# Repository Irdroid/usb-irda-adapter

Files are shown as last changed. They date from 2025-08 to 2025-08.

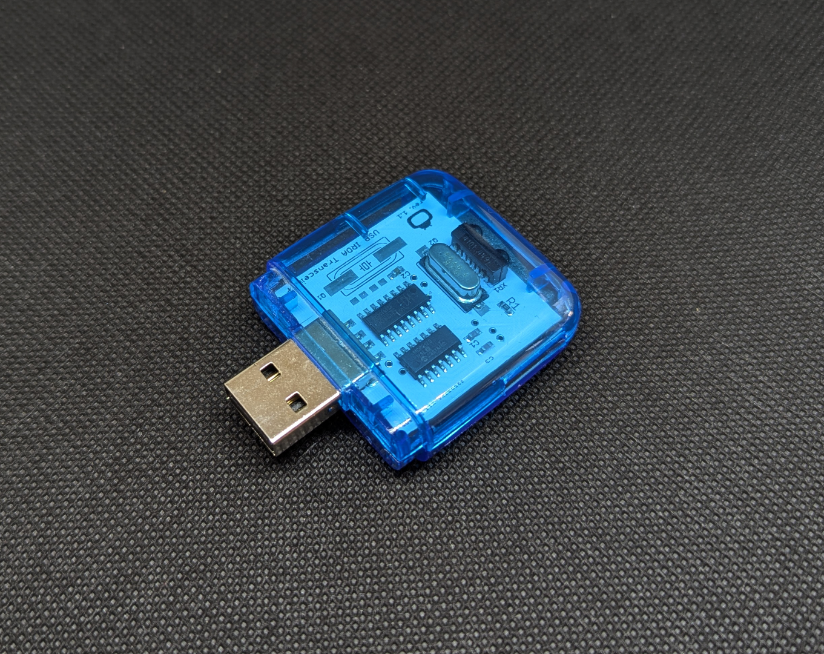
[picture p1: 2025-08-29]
Hardware/Pictures/irda_2 (Large).png

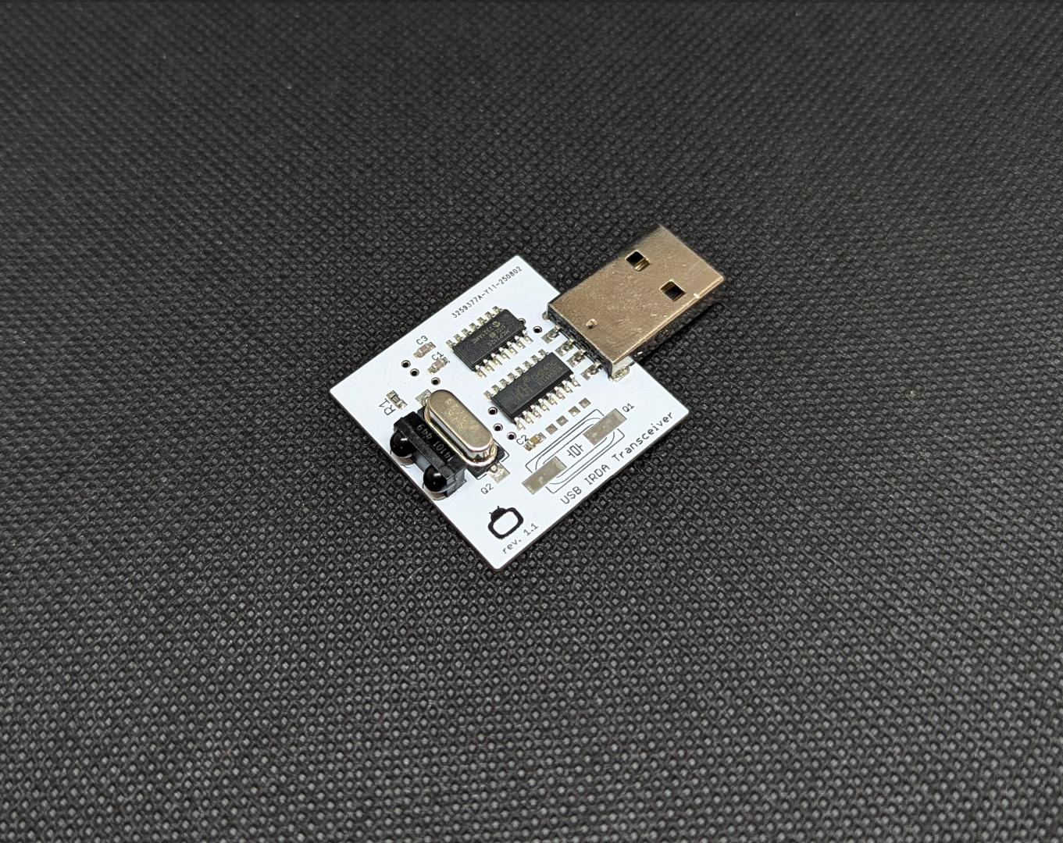
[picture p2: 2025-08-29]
Hardware/Pictures/irda_3 (Large).png

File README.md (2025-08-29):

# usb-irda-adapter
turns a USB port into an IrDA compliant infrared port for communication with IrDA devices on more recent operating systems

The USB irDA adapter is compatible with Windows 7, 10, 11 and Linux (older kernel versions, because the irDA stack was removed in recent kernel versions). 

Allows you to interface with irDA compliant devices, such as dive computers, medical instruments, power meters and more.

- Supports irDa SIR protocol (irDa spec. 1.3 )
- Supports Baud rates from 9600 to 115200
- Drivers for MS Windows 11 and 10
- USB 2.0 interface to the Host system.
- 2 meters line-of-sight irDa communication

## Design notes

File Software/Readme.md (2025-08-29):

USB irDA Adapter Device drivers for

- Windows 11
- Windows 10
- Windows 7

- [Installation instructions youtube video](https://www.youtube.com/watch?v=PCWln6I-PIc&t)

- [UWATEC dive computer irDa communication demo](https://www.youtube.com/watch?v=iUJTAUaZC4I)

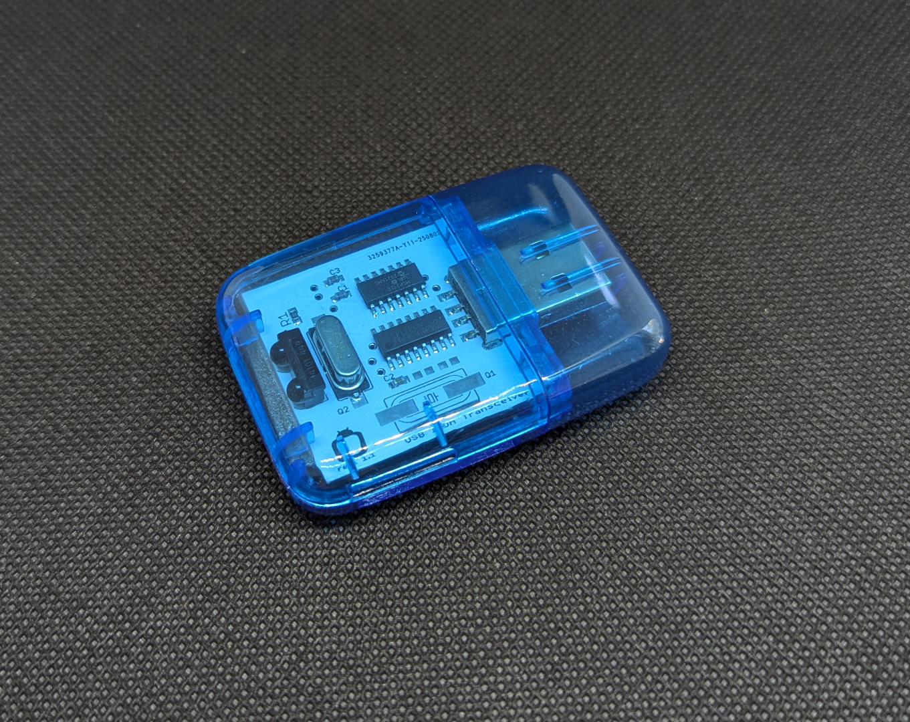
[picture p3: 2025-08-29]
Hardware/Pictures/irda_1 (Large).png

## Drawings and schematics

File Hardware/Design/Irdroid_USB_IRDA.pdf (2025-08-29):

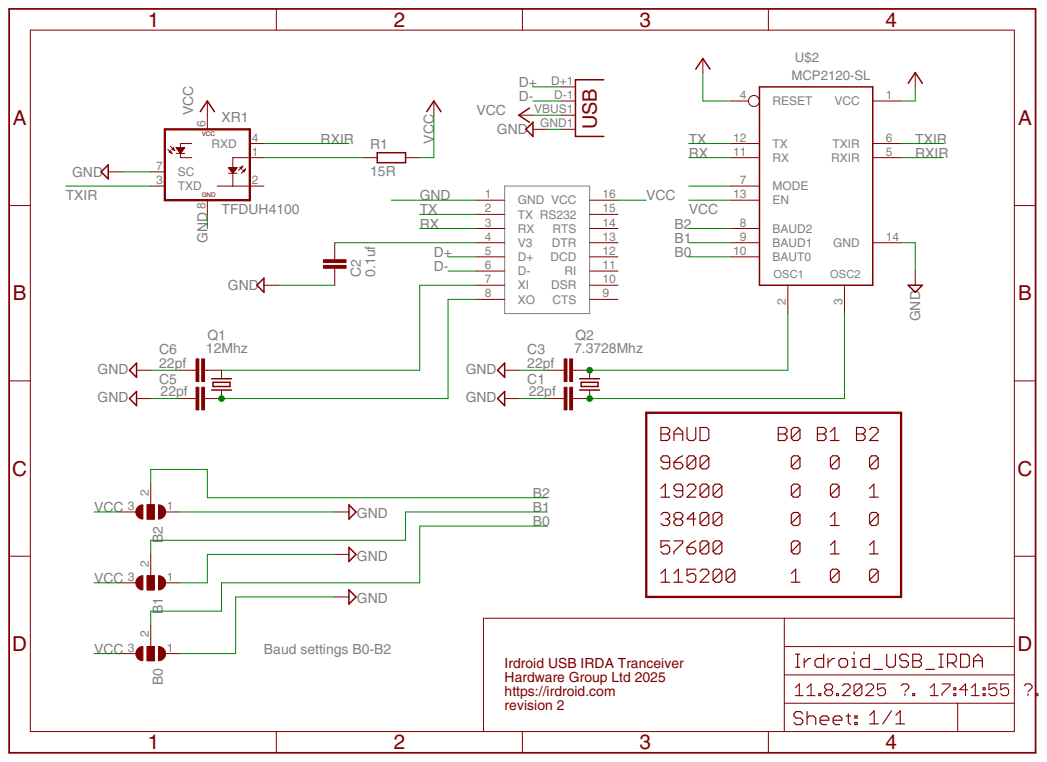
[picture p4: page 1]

Irdroid USB IRDA Tranceiver
Hardware Group Ltd 2025
https://irdroid.com
revision 2

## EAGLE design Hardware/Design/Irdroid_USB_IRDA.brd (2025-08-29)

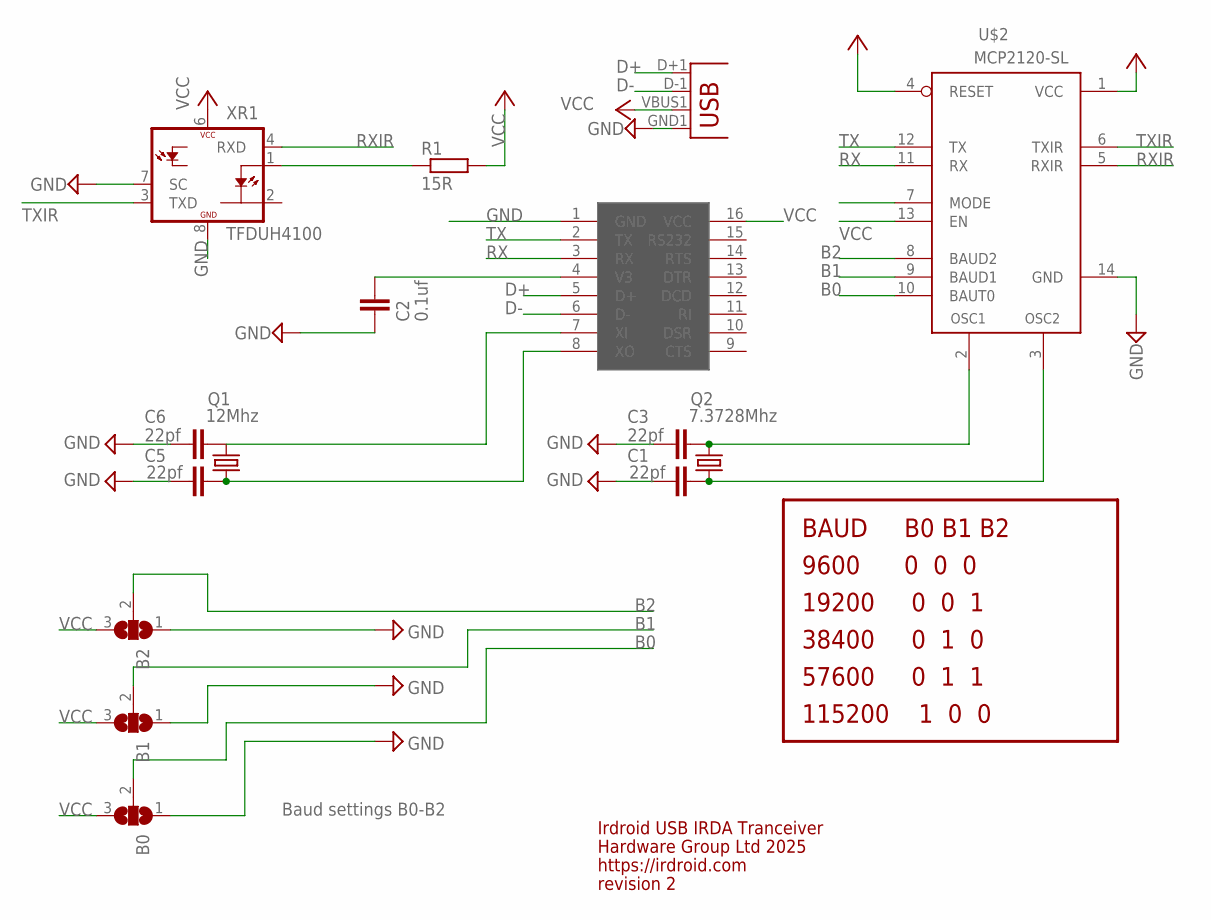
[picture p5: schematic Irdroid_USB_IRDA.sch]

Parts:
B0, B1, B2: SJ2W; SJ_2
C1, C3, C5, C6: 22pf; C603
C2: 0.1uf; C603
JP2: USBA-SMD-MALE; USB-A-SMT-MALE
Q1: 12Mhz; HC49UP
Q2: 7.3728Mhz; HC49UP
R1: 15R; R0603
U$1: ch; SOIC16
U$2: MCP2120-SL; SO-14
XR1: TFDUH4100; TFDU4-HOR

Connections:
B0: B0.2, U$2.10 (BAUT0)
B1: B1.2, U$2.9 (BAUD1)
B2: B2.2, U$2.8 (BAUD2)
D+: JP2.D+1 (D+), U$1.5 (D+)
D-: JP2.D-1 (D-), U$1.6 (D-)
GND: B0.1, B1.1, B2.1, C1.2, C2.2, C3.2, C5.2, C6.2, JP2.GND1 (GND), U$1.1 (GND), U$2.14 (GND), XR1.7 (SC), XR1.8 (GND)
unnamed: C5.1, Q1.1, U$1.8 (XO)
unnamed: C3.1, Q2.2, U$2.2 (OSC1)
unnamed: C6.1, Q1.2, U$1.7 (XI)
unnamed: C1.1, Q2.1, U$2.3 (OSC2)
unnamed: C2.1, U$1.4 (V3)
unnamed: R1.1, XR1.1 (IRED-A)
RX: U$1.3 (RX), U$2.11 (RX)
RXIR: U$2.5 (RXIR), XR1.4 (RXD)
TX: U$1.2 (TX), U$2.12 (TX)
TXIR: U$2.6 (TXIR), XR1.3 (TXD)
VCC: B0.3, B1.3, B2.3, JP2.VBUS1 (VBUS), R1.2, U$1.16 (VCC), U$2.1 (VCC), U$2.4 (RESET), U$2.7 (MODE), U$2.13 (EN), XR1.6 (VCC)

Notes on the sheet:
Hardware Group Ltd 2025
Irdroid USB IRDA Tranceiver
https://irdroid.com
Baud settings B0-B2
revision 2
9600 0 0 0
19200 0 0 1
38400 0 1 0
57600 0 1 1
115200 1 0 0
BAUD B0 B1 B2

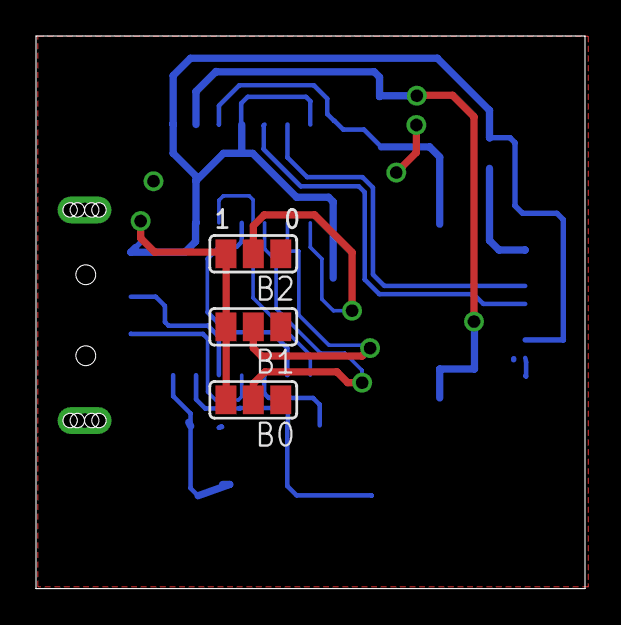
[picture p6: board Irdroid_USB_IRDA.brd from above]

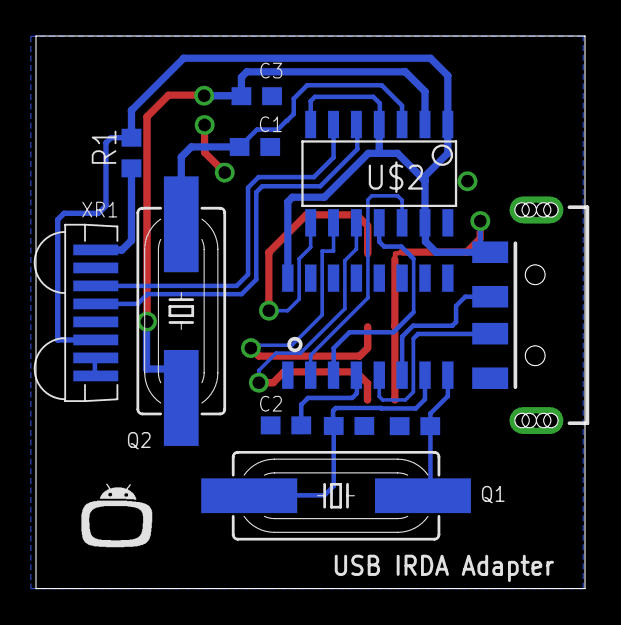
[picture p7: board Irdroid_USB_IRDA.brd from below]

Board: 2 copper layers, 30.5 x 30.7 mm, 15 parts (12 on the bottom side), 17 nets.

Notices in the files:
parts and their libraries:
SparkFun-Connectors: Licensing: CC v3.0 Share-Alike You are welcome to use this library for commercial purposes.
